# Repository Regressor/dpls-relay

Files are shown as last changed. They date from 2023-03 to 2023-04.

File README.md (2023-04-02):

# Реле для С2000-КДЛ (на базе таблички С2000-ОСТ)

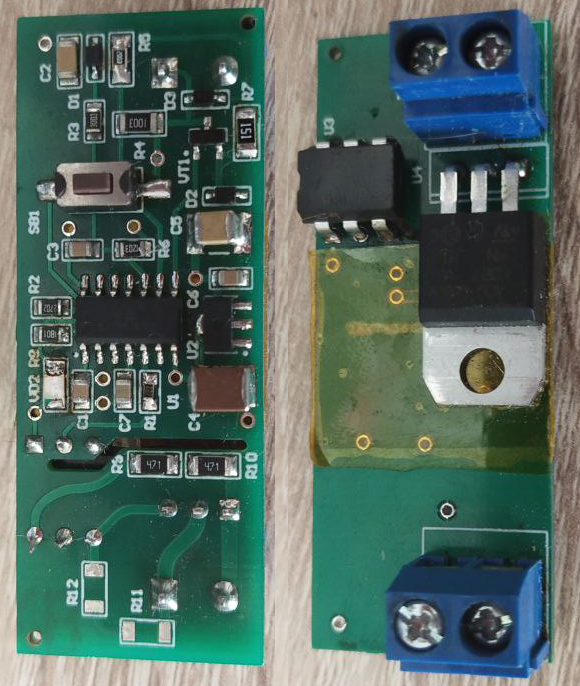
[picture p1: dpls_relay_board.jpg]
Фото устройства


Мне понадобилось на базе уже имеющейся адресной охрано-пожарной системы с ДПЛС шиной реализовать включение-выключение нагрузки 220В по команде пульта. При этом реле необходимо было установить в стандартный подрозетник.

Размеры С2000-СП к сожалению не подходили, поэтому было принято решение купить табличку С2000-ОСТ, снять с нее микроконтроллер, разработать плату для этого микроконтроллера размерами 21х54мм со всей 
необходимой обвязкой для работы шины ДПЛС и управления нагрузкой. Исходники платы в формате Kicad выкладываю в общий доступ.

Управление нагрузкой осуществляется с помощью симмистора BTA06-600. Опторазвязка сделана на базе IL4208 (потребление устройства ограничено шиной ДПЛС поэтому выбрана самая малопотребляющая опторазвязка).

Под симмистор я рекомендую на плату наклеить несколько слоев каптона во избежание замыкания (см. фото).

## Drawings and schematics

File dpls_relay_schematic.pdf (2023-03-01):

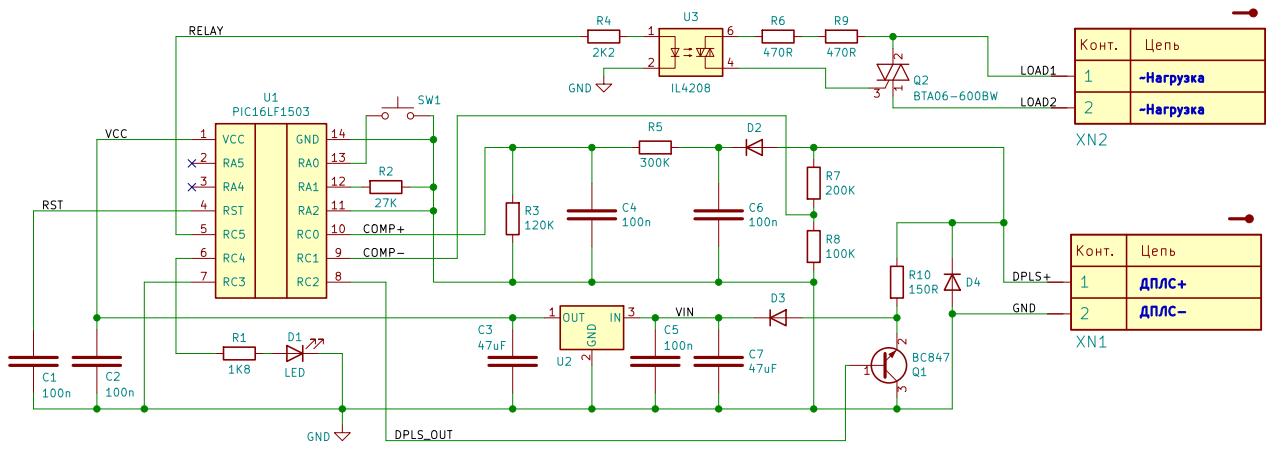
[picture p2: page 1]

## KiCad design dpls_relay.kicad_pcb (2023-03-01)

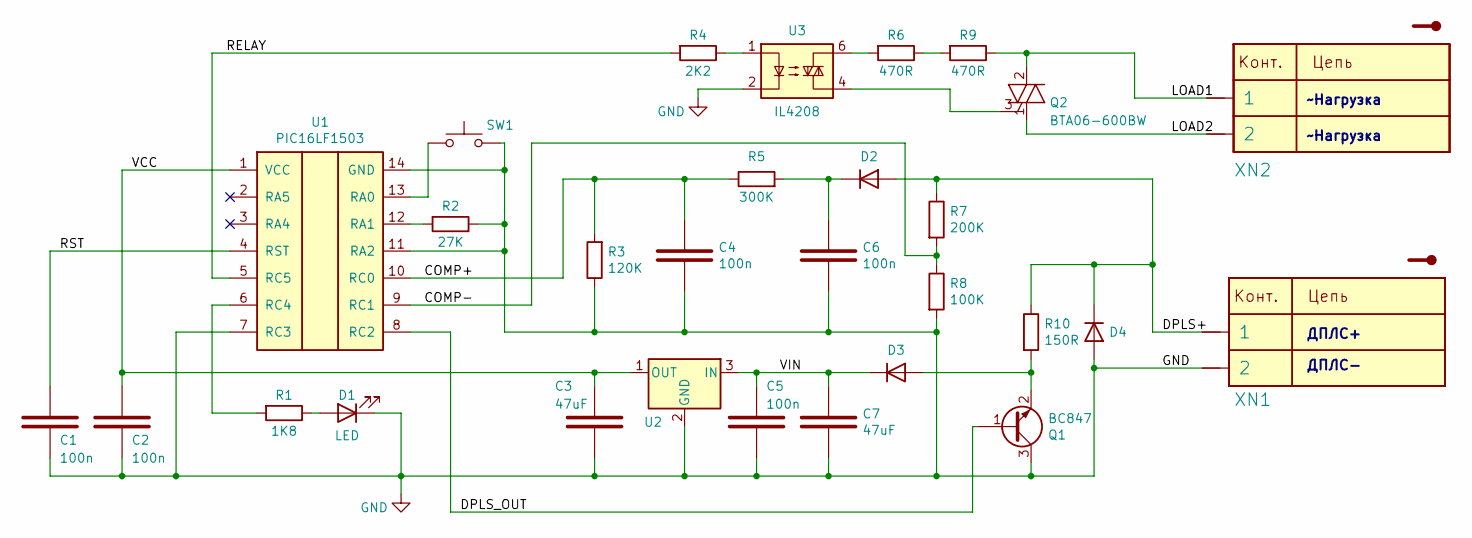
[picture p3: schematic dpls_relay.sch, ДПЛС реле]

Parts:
C1, C2, C4, C5, C6: 100n; C_0805_2012Metric
C3, C7: 47uF; C_1812_4532Metric
D1: LED; LED_0805_2012Metric
D2, D3, D4: PMEG4010BEA; D_SOD-323
Q1: BC847; SOT-23
Q2: BTA06-600BW; TO-220-3_Vertical
R1: 1K8; R_0805_2012Metric
R2: 27K; R_0805_2012Metric
R3: 120K; R_0805_2012Metric
R4: 2K2; R_0805_2012Metric
R5: 300K; R_0805_2012Metric
R6, R9: 470R; R_1206_3216Metric
R7: 200K; R_0805_2012Metric
R8: 100K; R_0805_2012Metric
R10: 150R; R_0805_2012Metric
SW1: SW_Push; SW_SPST_FSMSM
U1: PIC16LF1503; SO-14_3.9x8.65mm_P1.27mm
U2: L78L05; SOT-89-3
U3: IL4208; DIP-6_W7.62mm
XN1, XN2: HEAD_2PIN; KLS2-102

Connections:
/COMP+: C4.1, R3.2, R5.1, U1.10 (RC0)
/COMP-: R7.2, R8.1, U1.9 (RC1)
/DPLS+: D2.2 (A), D4.1 (K), R7.1, R10.1, XN1.1
/DPLS_OUT: Q1.1 (B), U1.8 (RC2)
/LOAD1: Q2.2, R9.1, XN2.1
/LOAD2: Q2.1, XN2.2
/RELAY: R4.2, U1.5 (RC5)
/RST: C1.1, U1.4 (RST)
/VCC: C2.2, C3.1, U1.1 (VCC), U2.1 (OUT)
/VIN: C5.1, C7.1, D3.1 (K), U2.3 (IN)
GND: C1.2, C2.1, C3.2, C4.2, C5.2, C6.2, C7.2, D1.1 (K), D4.2 (A), Q1.3 (C), R2.1, R3.1, R8.2, SW1.2, U1.7 (RC3), U1.11 (RA2), U1.14 (GND), U2.2 (GND), U3.2, XN1.2
unnamed: C6.1, D2.1 (K), R5.2
unnamed: D1.2 (A), R1.1
unnamed: D3.2 (A), Q1.2 (E), R10.2
unnamed: Q2.3, U3.4
unnamed: R1.2, U1.6 (RC4)
unnamed: R2.2, U1.12 (RA1)
unnamed: R4.1, U3.1
unnamed: R6.1, R9.2
unnamed: R6.2, U3.6
unnamed: SW1.1, U1.13 (RA0)

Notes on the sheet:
ДПЛС+
ДПЛС-
~~Нагрузка

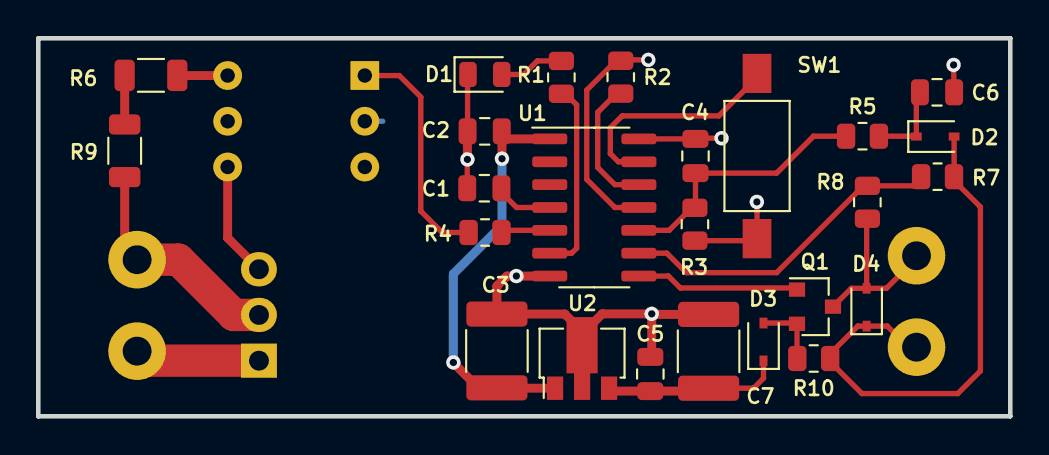
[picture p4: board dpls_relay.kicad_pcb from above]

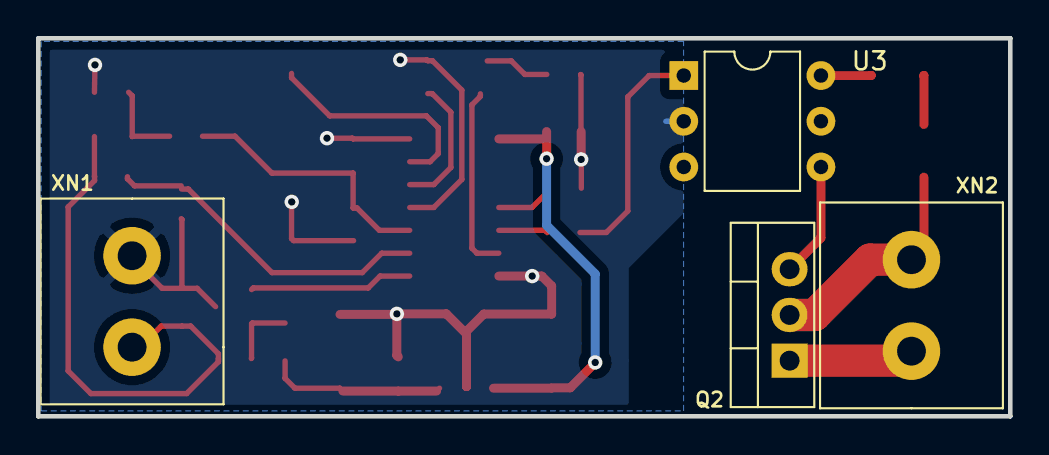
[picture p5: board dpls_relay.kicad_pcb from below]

Board: 2 copper layers, 54.0 x 21.0 mm, 29 parts (4 on the bottom side), 21 nets.

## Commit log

2023-03-01 Добавлены исходники платы и схемы, а также фотография
    [dpls_relay.kicad_pcb, dpls_relay.sch]
2023-03-01 Добавлена схема в формате pdf
2023-04-02 Update README.md
    Поправлен заголовок
